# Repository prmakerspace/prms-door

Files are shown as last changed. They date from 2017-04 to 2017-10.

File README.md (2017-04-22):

# prms-door
## Powell River Makerspace Door Project

RFID door lock for our Makerspace

### Usage:
#### To enter:
1.  scan card at door
1.  door unlocks
1.  enter; door relocks after 15 seconds

#### To exit:
1.  scan card at door
1.  door unlocks
1.  exit; door relocks after 15 seconds

#### To add a new member:
1.  ssh into the raspberry pi
1.  `cd prms-door`
1.  `./writeCard.py` to get a list of possible users
1.  `./writeCard.py -h` to get a list of options (to replace a card for a user)
1.  `./writeCard.py memberId` to write a member's id to a card; follow on-screen instructions
1.  test the new card

## Setup (big picture, details to come):
1.  Check out from git
1.  Install the pigpio library from abyz.co.uk/rpi/pigpio/
1.  Install any other missing modules.  Note that we include a modified MFRC522 library.
1.  Change to be executable:
    chmod a+x door.py
    chmod a+x fetchMembers.py
    chmod a+x writeCard.py
1.  Connect card reader as documented on the internet - we use a standard connection.
1.  Connect the servo to GPIO pin 14, 5v, and ground.
1.  Add cron entries via `sudo crontab -e`
    @reboot pigpiod
    @reboot sleep 30 && /home/pi/prms-door/door.py &
    @daily  sleep 30 && /home/pi/prms-door/fetchMembers.py &

Required features:
1.  current access control (keys) still work (needs testing)
1.  ~~members can scan an rfid card/key fob; door unlocks~~
1.  ~~the door can be unlocked from inside~~
1.  ~~new members are added by entering the key card id into the member database manually~~

Optional features:
1.  door can be unlocked from inside without a rfid key/card
1.  ~~list of members is updated from our website~~
  * ~~non-paying members are removed from the list automatically~~
1.  there's a way to scan new members into the system
1.  the door knows it's open 
  * and won't lock until closed
  * and will alarm if left open, until a card is swiped
1.  there's a camera connected
  * that takes video when the card is swiped?
  * that takes video when the door is opened?
  * that allows people to see if there's anybody in the Makerspace
  * that can be used for training machine learning to see if there's anybody in the space

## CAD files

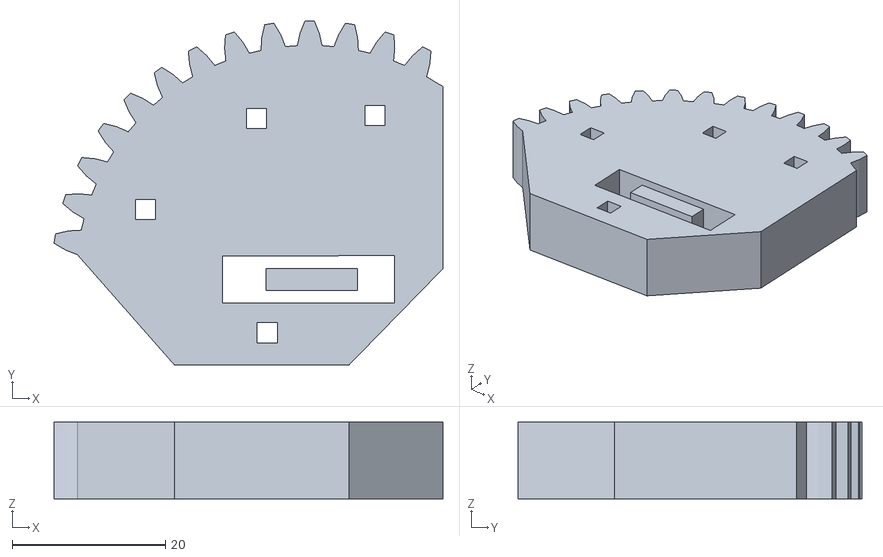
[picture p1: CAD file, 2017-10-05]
prmsdoorgear1.stl
50.8 x 45.0 x 10.0

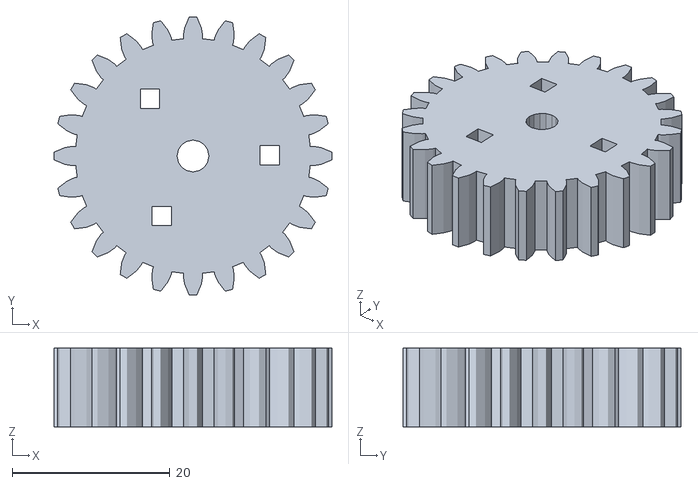
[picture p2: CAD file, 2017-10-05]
prmsdoorgear2.stl
35.3 x 35.3 x 10.0

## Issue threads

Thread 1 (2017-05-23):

Servo burns out

tgray-projects, 2017-05-23:
If the door isn't quite closed, the servo will still attempt to actuate, driving the deadbolt into position.  There is no feedback to the system that this is happening, and the servo will continue to push, burning out the DC motor in the servo.

Additionally, the door stays unlocked during this event, when it appears to be locked to casual observation.

To reproduce, first have a spare servo.

1. Close the door such that the door appears closed, but there is a small gap between the inside of the door frame and the door of about 1cm.
2. Let the door attempt to lock; you will hear the servo actuate, but the latch will not engage fully.
3. Leave it overnight, or until the servo burns out.  During this time, the door can still be opened without engaging the lock system.
4. Replace servo to resume normal operation.

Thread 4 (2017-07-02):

Physical flaws

thomas-keynexus, 2017-07-02:
Physical parts of the device (mounting point, gears) don't stay attached or fit too loosely.  Having them come off causes issues with operability of the system, and not all members can easily replace/repair them.

eladam14, 2017-07-02:
I agree with the idea of using a card to come and go, but feel the application should have the bugs ironed out before becoming the only way to come and go. Individual keys should be supplied to all members until that time.

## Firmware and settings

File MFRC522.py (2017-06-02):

import RPi.GPIO as GPIO
import spi
import signal
import time
  
class MFRC522:
  NRSTPD = 22
  
  MAX_LEN = 16
  
  PCD_IDLE       = 0x00
  PCD_AUTHENT    = 0x0E
  PCD_RECEIVE    = 0x08
  PCD_TRANSMIT   = 0x04
  PCD_TRANSCEIVE = 0x0C
  PCD_RESETPHASE = 0x0F
  PCD_CALCCRC    = 0x03
  
  PICC_REQIDL    = 0x26
  PICC_REQALL    = 0x52
  PICC_ANTICOLL  = 0x93
  PICC_SElECTTAG = 0x93
  PICC_AUTHENT1A = 0x60
  PICC_AUTHENT1B = 0x61
  PICC_READ      = 0x30
  PICC_WRITE     = 0xA0
  PICC_DECREMENT = 0xC0
  PICC_INCREMENT = 0xC1
  PICC_RESTORE   = 0xC2
  PICC_TRANSFER  = 0xB0
  PICC_HALT      = 0x50
  
  MI_OK       = 0
  MI_NOTAGERR = 1
  MI_ERR      = 2
  
  Reserved00     = 0x00
  CommandReg     = 0x01
  CommIEnReg     = 0x02
  DivlEnReg      = 0x03
  CommIrqReg     = 0x04
  DivIrqReg      = 0x05
  ErrorReg       = 0x06
  Status1Reg     = 0x07
  Status2Reg     = 0x08
  FIFODataReg    = 0x09
  FIFOLevelReg   = 0x0A
  WaterLevelReg  = 0x0B
  ControlReg     = 0x0C
  BitFramingReg  = 0x0D
  CollReg        = 0x0E
  Reserved01     = 0x0F
  
  Reserved10     = 0x10
  ModeReg        = 0x11
  TxModeReg      = 0x12
  RxModeReg      = 0x13
  TxControlReg   = 0x14
  TxAutoReg      = 0x15
  TxSelReg       = 0x16
  RxSelReg       = 0x17
  RxThresholdReg = 0x18
  DemodReg       = 0x19
  Reserved11     = 0x1A
  Reserved12     = 0x1B
  MifareReg      = 0x1C
  Reserved13     = 0x1D
  Reserved14     = 0x1E
  SerialSpeedReg = 0x1F
  
  Reserved20        = 0x20  
  CRCResultRegM     = 0x21
  CRCResultRegL     = 0x22
  Reserved21        = 0x23
  ModWidthReg       = 0x24
  Reserved22        = 0x25
  RFCfgReg          = 0x26
  GsNReg            = 0x27
  CWGsPReg          = 0x28
  ModGsPReg         = 0x29
  TModeReg          = 0x2A
  TPrescalerReg     = 0x2B
  TReloadRegH       = 0x2C
  TReloadRegL       = 0x2D
  TCounterValueRegH = 0x2E
  TCounterValueRegL = 0x2F
  
  Reserved30      = 0x30
  TestSel1Reg     = 0x31
  TestSel2Reg     = 0x32
  TestPinEnReg    = 0x33
  TestPinValueReg = 0x34
  TestBusReg      = 0x35
  AutoTestReg     = 0x36
  VersionReg      = 0x37
  AnalogTestReg   = 0x38
  TestDAC1Reg     = 0x39
  TestDAC2Reg     = 0x3A
  TestADCReg      = 0x3B
  Reserved31      = 0x3C
  Reserved32      = 0x3D
  Reserved33      = 0x3E
  Reserved34      = 0x3F
    
  serNum = []
  
  def __init__(self,spd=1000000):
    spi.openSPI(speed=spd)
    GPIO.setmode(GPIO.BOARD)
    GPIO.setup(22, GPIO.OUT)
    GPIO.output(self.NRSTPD, 1)
    self.MFRC522_Init()
  
  def MFRC522_Reset(self):
    self.Write_MFRC522(self.CommandReg, self.PCD_RESETPHASE)
  
  def Write_MFRC522(self,addr,val):
    spi.transfer(((addr<<1)&0x7E,val))
  
  def Read_MFRC522(self,addr):
    val = spi.transfer((((addr<<1)&0x7E) | 0x80,0))
    return val[1]
  
  def SetBitMask(self, reg, mask):
    tmp = self.Read_MFRC522(reg)
    self.Write_MFRC522(reg, tmp | mask)
    
  def ClearBitMask(self, reg, mask):
    tmp = self.Read_MFRC522(reg);
    self.Write_MFRC522(reg, tmp & (~mask))
  
  def AntennaOn(self):
    temp = self.Read_MFRC522(self.TxControlReg)
    if(~(temp & 0x03)):
      self.SetBitMask(self.TxControlReg, 0x03)
  
  def AntennaOff(self):
    self.ClearBitMask(self.TxControlReg, 0x03)
  
  def MFRC522_ToCard(self,command,sendData):
    backData = []
    backLen = 0
    status = self.MI_ERR
    irqEn = 0x00
    waitIRq = 0x00
    lastBits = None
    n = 0
    i = 0
    
    if command == self.PCD_AUTHENT:
      irqEn = 0x12
      waitIRq = 0x10
    if command == self.PCD_TRANSCEIVE:
      irqEn = 0x77
      waitIRq = 0x30
    
    self.Write_MFRC522(self.CommIEnReg, irqEn|0x80)
    self.ClearBitMask(self.CommIrqReg, 0x80)
    self.SetBitMask(self.FIFOLevelReg, 0x80)
    
    self.Write_MFRC522(self.CommandReg, self.PCD_IDLE);  
    
    while(i<len(sendData)):
      self.Write_MFRC522(self.FIFODataReg, sendData[i])
      i = i+1
    
    self.Write_MFRC522(self.CommandReg, command)
      
    if command == self.PCD_TRANSCEIVE:
      self.SetBitMask(self.BitFramingReg, 0x80)
    
    i = 2000
    while True:
      n = self.Read_MFRC522(self.CommIrqReg)
      i = i - 1
      if ~((i!=0) and ~(n&0x01) and ~(n&waitIRq)):
        break
    
    self.ClearBitMask(self.BitFramingReg, 0x80)
  
    if i != 0:
      if (self.Read_MFRC522(self.ErrorReg) & 0x1B)==0x00:
        status = self.MI_OK

        if n & irqEn & 0x01:
          status = self.MI_NOTAGERR
      
        if command == self.PCD_TRANSCEIVE:
          n = self.Read_MFRC522(self.FIFOLevelReg)
          lastBits = self.Read_MFRC522(self.ControlReg) & 0x07
          if lastBits != 0:
            backLen = (n-1)*8 + lastBits
          else:
            backLen = n*8
          
          if n == 0:
            n = 1
          if n > self.MAX_LEN:
            n = self.MAX_LEN
    
          i = 0
          while i<n:
            backData.append(self.Read_MFRC522(self.FIFODataReg))
            i = i + 1;
      else:
        status = self.MI_ERR
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

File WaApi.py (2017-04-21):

r"""
This module provides set of classes for working with WildApricot public API v2.
Public API documentation can be found here: http://help.wildapricot.com/display/DOC/API+Version+2
Example:
    api = WaApi.WaApiClient()
    api.authenticate_with_contact_credentials("admin@youraccount.com", "your_password")
    accounts = api.execute_request("/v2/accounts")
    for account in accounts:
        print(account.PrimaryDomainName)
"""

__author__ = 'dsmirnov@wildapricot.com'

import datetime
import urllib.request
import urllib.response
import urllib.error
import urllib.parse
import json
import base64


class WaApiClient(object):
    """Wild apricot API client."""
    auth_endpoint = "https://oauth.wildapricot.org/auth/token"
    api_endpoint = "https://api.wildapricot.org"
    _token = None
    client_id = None
    client_secret = None

    def __init__(self, client_id, client_secret):
        self.client_id = client_id
        self.client_secret = client_secret

    def authenticate_with_apikey(self, api_key, scope=None):
        """perform authentication by api key and store result for execute_request method
        api_key -- secret api key from account settings
        scope -- optional scope of authentication request. If None full list of API scopes will be used.
        """
        scope = "auto" if scope is None else scope
        data = {
            "grant_type": "client_credentials",
            "scope": scope
        }
        encoded_data = urllib.parse.urlencode(data).encode()
        request = urllib.request.Request(self.auth_endpoint, encoded_data, method="POST")
        request.add_header("ContentType", "application/x-www-form-urlencoded")
        request.add_header("Authorization", 'Basic ' + base64.standard_b64encode(('APIKEY:' + api_key).encode()).decode())
        response = urllib.request.urlopen(request)
        self._token = WaApiClient._parse_response(response)
        self._token.retrieved_at = datetime.datetime.now()

    def authenticate_with_contact_credentials(self, username, password, scope=None):
        """perform authentication by contact credentials and store result for execute_request method
        username -- typically a contact email
        password -- contact password
        scope -- optional scope of authentication request. If None full list of API scopes will be used.
        """
        scope = "auto" if scope is None else scope
        data = {
            "grant_type": "password",
            "username": username,
            "password": password,
            "scope": scope
        }
        encoded_data = urllib.parse.urlencode(data).encode()
        request = urllib.request.Request(self.auth_endpoint, encoded_data, method="POST")
        request.add_header("ContentType", "application/x-www-form-urlencoded")
        auth_header = base64.standard_b64encode((self.client_id + ':' + self.client_secret).encode()).decode()
        request.add_header("Authorization", 'Basic ' + auth_header)
        response = urllib.request.urlopen(request)
        self._token = WaApiClient._parse_response(response)
        self._token.retrieved_at = datetime.datetime.now()

    def execute_request(self, api_url, api_request_object=None, method=None):
        """
        perform api request and return result as an instance of ApiObject or list of ApiObjects
        api_url -- absolute or relative api resource url
        api_request_object -- any json serializable object to send to API
        method -- HTTP method of api request. Default: GET if api_request_object is None else POST
        """
        if self._token is None:
            raise ApiException("Access token is not abtained. "
                               "Call authenticate_with_apikey or authenticate_with_contact_credentials first.")

        if not api_url.startswith("http"):
            api_url = self.api_endpoint + api_url

        if method is None:
            if api_request_object is None:
                method = "GET"
            else:
                method = "POST"

        request = urllib.request.Request(api_url, method=method)
        if api_request_object is not None:
            request.data = json.dumps(api_request_object, cls=_ApiObjectEncoder).encode()

        request.add_header("Content-Type", "application/json")
        request.add_header("Accept", "application/json")
        request.add_header("Authorization", "Bearer " + self._get_access_token())

        try:
            response = urllib.request.urlopen(request)
            return WaApiClient._parse_response(response)
        except urllib.error.HTTPError as httpErr:
            if httpErr.code == 400:
                raise ApiException(httpErr.read())
            else:
                raise

    def _get_access_token(self):
        expires_at = self._token.retrieved_at + datetime.timedelta(seconds=self._token.expires_in - 100)
        if datetime.datetime.utcnow() > expires_at:
            self._refresh_auth_token()
        return self._token.access_token

    def _refresh_auth_token(self):
        data = {
            "grant_type": "refresh_token",
            "refresh_token": self._token.refresh_token
        }
        encoded_data = urllib.parse.urlencode(data).encode()
        request = urllib.request.Request(self.auth_endpoint, encoded_data, method="POST")
        request.add_header("ContentType", "application/x-www-form-urlencoded")
        auth_header = base64.standard_b64encode((self.client_id + ':' + self.client_secret).encode()).decode()
        request.add_header("Authorization", 'Basic ' + auth_header)
        response = urllib.request.urlopen(request)
        self._token = WaApiClient._parse_response(response)
        self._token.retrieved_at = datetime.datetime.now()

    @staticmethod
    def _parse_response(http_response):
        decoded = json.loads(http_response.read().decode())
        if isinstance(decoded, list):
            result = []
            for item in decoded:
                result.append(ApiObject(item))
            return result
        elif isinstance(decoded, dict):
            return ApiObject(decoded)
        else:
            return None


class ApiException(Exception):
    def __init__(self, value):
        self.value = value

    def __str__(self):
        return repr(self.value)
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

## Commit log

2017-04-22 updated files to have correct python version, updated README
    [door.py, fetchMembers.py, writeCard.py]
2017-04-22 Update new member instructions; fixed variable name confusion (member status vs card status); added better error message.
    [writeCard.py]
2017-05-10 Minor code cleanup and reverse locked/unlocked position for final installation and placement.
    [door.py]
2017-06-01 Move from 'print' to proper logging
2017-06-01 Improve logging - add file and try/except around likely failure point.
    [door.py]
2017-06-08 Issues with the door seem to be related to database timeout; changed code such that the database connection is only made as needed, then closed.
    [door.py]
2017-07-02 Initial checkin of laser cut door pieces, including mounting plate and gears.
2017-07-02 updated door gears; different ratio
2017-07-02 updated door gears; different ratio, better design
2017-10-05 Uploading gear stl files for 3d printing
    Files from Fran, based on svg files.
    [prmsdoorgear1.stl, prmsdoorgear2.stl]
